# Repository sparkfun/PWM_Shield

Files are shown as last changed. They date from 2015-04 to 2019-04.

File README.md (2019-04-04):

**NOTE:** *This product has been retired from our catalog. If you are looking for more up-to-date info, please check out some of these resources to see how other users are still hacking and improving on this product.*
* *[SparkFun Forum](https://forum.sparkfun.com/)*
* *[Comments Here on GitHub](https://github.com/sparkfun/PWM_Shield/issues)*
* *[IRC Channel](https://www.sparkfun.com/news/263)*

SparkFun PWM Shield
========================================

SparkFun PWM Shield

[*SparkFun PWM Shield (DEV-10615)*](https://www.sparkfun.com/products/10615)

This is the Arduino shield version of our TLC5940 Breakout. 
The SparkFun PWM Shield will allow you to generate up to 16 PWM signals from your Arduino by utilizing the power of the TLC5940 IC. 

Repository Contents
-------------------

* **/Hardware** - Eagle design files (.brd, .sch)
* **/Libraries** - Libraries for use with the TLC5940
* **/Production** - Production panel files (.brd)

Documentation
--------------
* **[Library](https://github.com/sparkfun/SparkFun_TLC5940_Arduino_Library)** - Arduino Library for the TLC5940. 
* **[SparkFun Fritzing repo](https://github.com/sparkfun/Fritzing_Parts)** - Fritzing diagrams for SparkFun products.
* **[SparkFun 3D Model repo](https://github.com/sparkfun/3D_Models)** - 3D models of SparkFun products. 

License Information
-------------------
This product is _**open source**_! 

The **hardware** is released under [Creative Commons ShareAlike 4.0 International](https://creativecommons.org/licenses/by-sa/4.0/).

Please use, reuse, and modify these files as you see fit. Please maintain attribution to SparkFun Electronics and release anything derivative under the same license.

Distributed as-is; no warranty is given.

- Your friends at SparkFun.

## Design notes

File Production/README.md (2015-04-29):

SparkFun Production Files
=========================

These .brd files are the panels we use for producing large numbers of pcbs.

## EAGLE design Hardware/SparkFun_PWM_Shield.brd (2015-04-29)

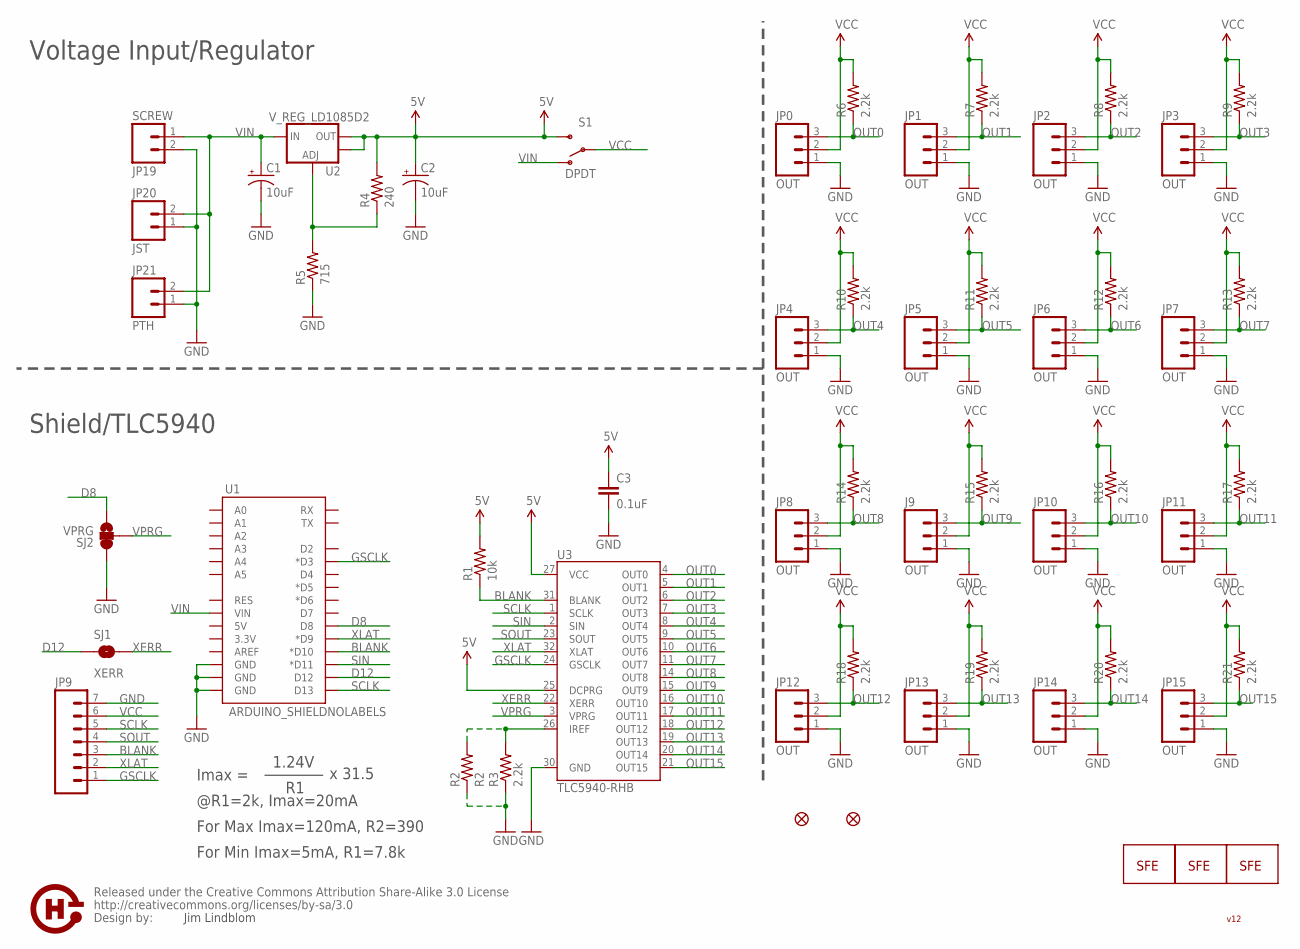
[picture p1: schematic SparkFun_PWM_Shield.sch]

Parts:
C1: 10uF; EIA3528
C2: 10uF; EIA3216
C3: 0.1uF; 0402-CAP
J9: OUT; 1X03
JP0, JP1, JP2, JP3, JP4, JP5, JP6, JP7, JP8, JP10, JP11, JP12, JP13, JP14, JP15: OUT; 1X03
JP9: M07; 1X07
JP16: LOGO-SFENEW; SFE-NEW-WEBLOGO
JP17: LOGO-SFESK; SFE-LOGO-FLAME
JP18: LOGO-SFENW2; SFE-NEW-WEB
JP19: SCREW; SCREWTERMINAL-3.5MM-2-NS
JP20: JST; JST-2-PTH
JP21: PTH; 1X02
JP22, JP23: FIDUCIAL1X2; FIDUCIAL-1X2
R1: 10k; 0402-RES
R2: R2; AXIAL-0.3
R3, R6, R7, R8, R9, R10, R11, R12, R13, R14, R15, R16, R17, R18, R19, R20, R21: 2.2k; 0402-RES
R4: 240; 0402-RES
R5: 715; 0402-RES
S1: DPDT; AYZ0202
SJ1: XERR; SJ_2S-NO
SJ2: VPRG; SJ_3
U1: ARDUINO_SHIELDNOLABELS; DUEMILANOVE_SHIELD_NOLABELS
U2: V_REG_LD1085D2; D2PACK/A
U3: TLC5940-RHB; QFN-32
U$1: OSHW-LOGOORB; OSHW-LOGO-GO
U$2: CREATIVE_COMMONS

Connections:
5V: C2.A (+), C3.1, R1.2, R4.2, S1.3 (S), U2.2 (OUT), U2.TAB (OUT), U3.25 (DCPRG), U3.27 (VCC)
BLANK: JP9.3, R1.1, U1.D10 (*D10), U3.31 (BLANK)
D8: SJ2.3, U1.D8
D12: SJ1.1, U1.D12
GND: C1.C (-), C2.C (-), C3.2, J9.1, JP0.1, JP1.1, JP2.1, JP3.1, JP4.1, JP5.1, JP6.1, JP7.1, JP8.1, JP9.7, JP10.1, JP11.1, JP12.1, JP13.1, JP14.1, JP15.1, JP19.2, JP20.1, JP21.1, R2.P$1 (1), R3.1, R5.1, SJ2.1, U1.GND@0 (GND), U1.GND@1 (GND), U1.GND@2 (GND), U3.30 (GND)
GSCLK: JP9.1, U1.D3 (*D3), U3.24 (GSCLK)
unnamed: R4.1, R5.2, U2.1 (ADJ)
unnamed: R2.P$2 (2), R3.2, U3.26 (IREF)
OUT0: JP0.3, R6.1, U3.4 (OUT0)
OUT1: JP1.3, R7.1, U3.5 (OUT1)
OUT2: JP2.3, R8.1, U3.6 (OUT2)
OUT3: JP3.3, R9.1, U3.7 (OUT3)
OUT4: JP4.3, R10.1, U3.8 (OUT4)
OUT5: JP5.3, R11.1, U3.9 (OUT5)
OUT6: JP6.3, R12.1, U3.10 (OUT6)
OUT7: JP7.3, R13.1, U3.11 (OUT7)
OUT8: JP8.3, R14.1, U3.14 (OUT8)
OUT9: J9.3, R15.1, U3.15 (OUT9)
OUT10: JP10.3, R16.1, U3.16 (OUT10)
OUT11: JP11.3, R17.1, U3.17 (OUT11)
OUT12: JP12.3, R18.1, U3.18 (OUT12)
OUT13: JP13.3, R19.1, U3.19 (OUT13)
OUT14: JP14.3, R20.1, U3.20 (OUT14)
OUT15: JP15.3, R21.1, U3.21 (OUT15)
SCLK: JP9.5, U1.D13, U3.1 (SCLK)
SIN: U1.D11 (*D11), U3.2 (SIN)
SOUT: JP9.4, U3.23 (SOUT)
VCC: J9.2, JP0.2, JP1.2, JP2.2, JP3.2, JP4.2, JP5.2, JP6.2, JP7.2, JP8.2, JP9.6, JP10.2, JP11.2, JP12.2, JP13.2, JP14.2, JP15.2, R6.2, R7.2, R8.2, R9.2, R10.2, R11.2, R12.2, R13.2, R14.2, R15.2, R16.2, R17.2, R18.2, R19.2, R20.2, R21.2, S1.2
VIN: C1.A (+), JP19.1, JP20.2, JP21.2, S1.1 (O), U1.VIN, U2.3 (IN)
VPRG: SJ2.2, U3.3 (VPRG)
XERR: SJ1.2, U3.22 (XERR)
XLAT: JP9.2, U1.D9 (*D9), U3.32 (XLAT)

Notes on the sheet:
Imax =
1.24V
x 31.5
@R1=2k, Imax=20mA
For Max Imax=120mA, R2=390
For Min Imax=5mA, R1=7.8k
Jim Lindblom
Shield/TLC5940
Voltage Input/Regulator
v12

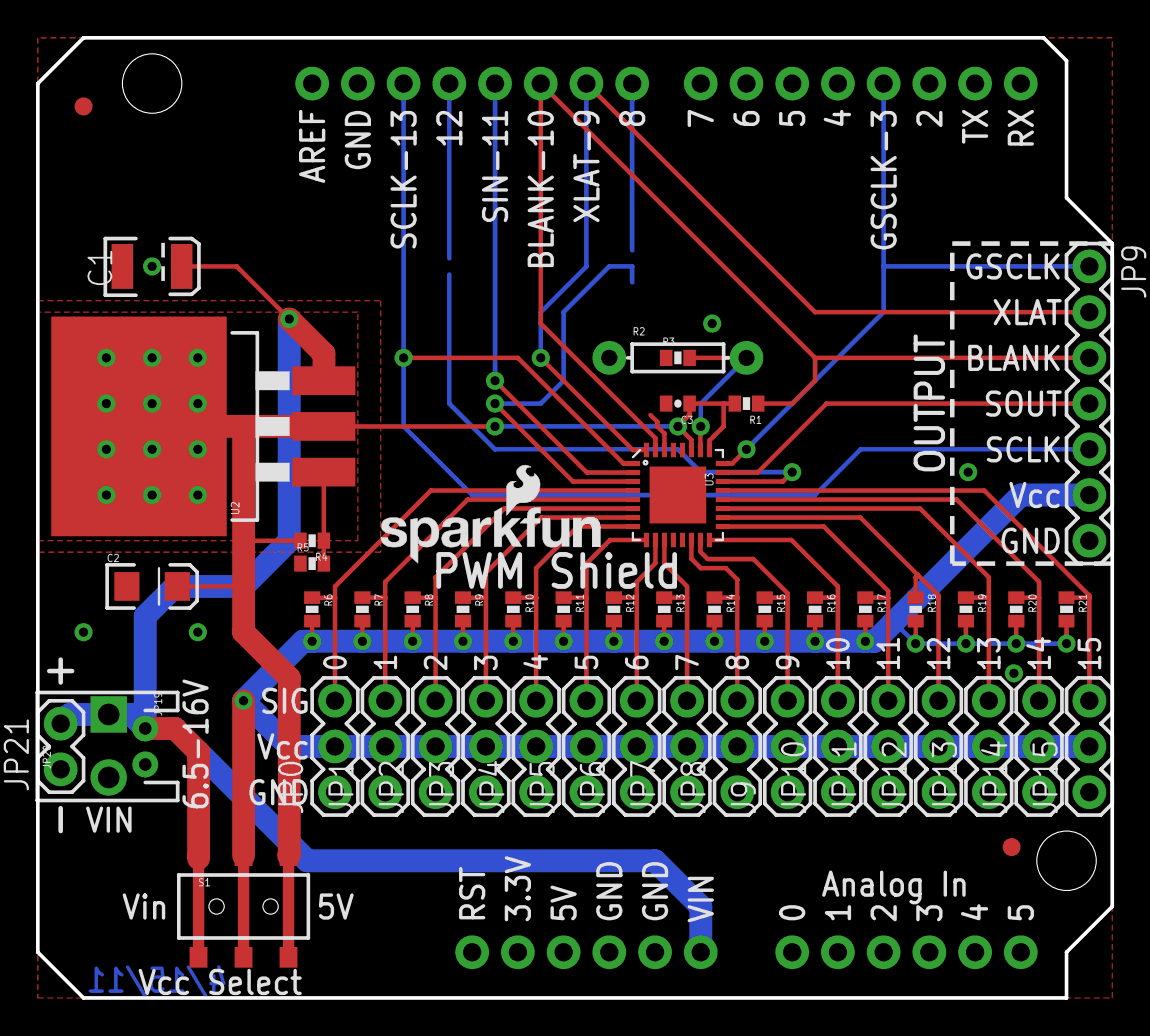
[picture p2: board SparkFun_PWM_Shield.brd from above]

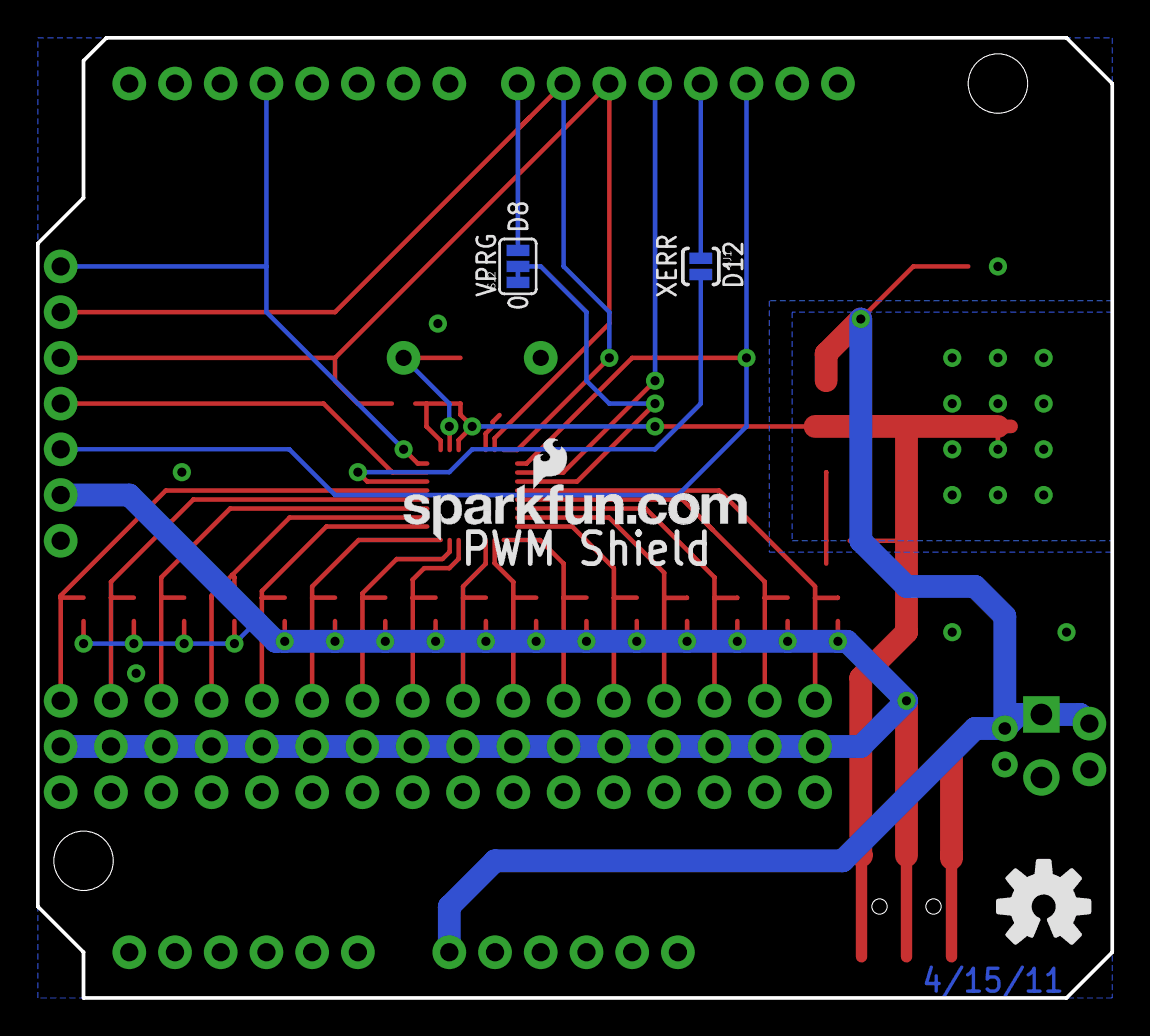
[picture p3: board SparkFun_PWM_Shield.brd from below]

Board: 2 copper layers, 59.7 x 53.3 mm, 57 parts (4 on the bottom side), 32 nets.

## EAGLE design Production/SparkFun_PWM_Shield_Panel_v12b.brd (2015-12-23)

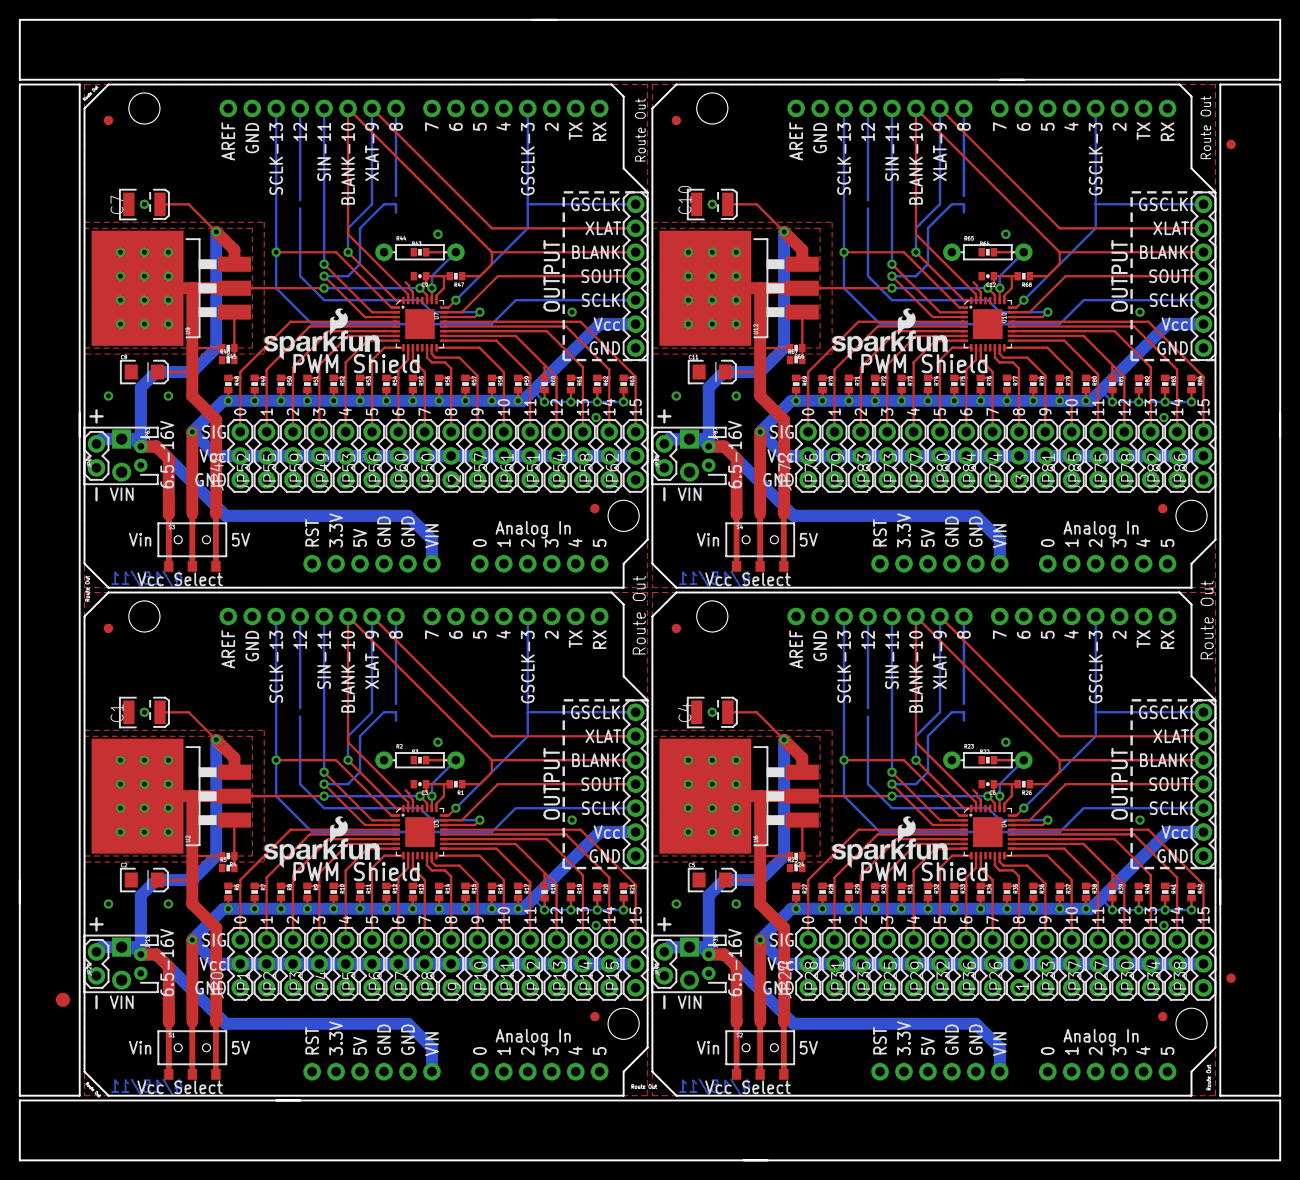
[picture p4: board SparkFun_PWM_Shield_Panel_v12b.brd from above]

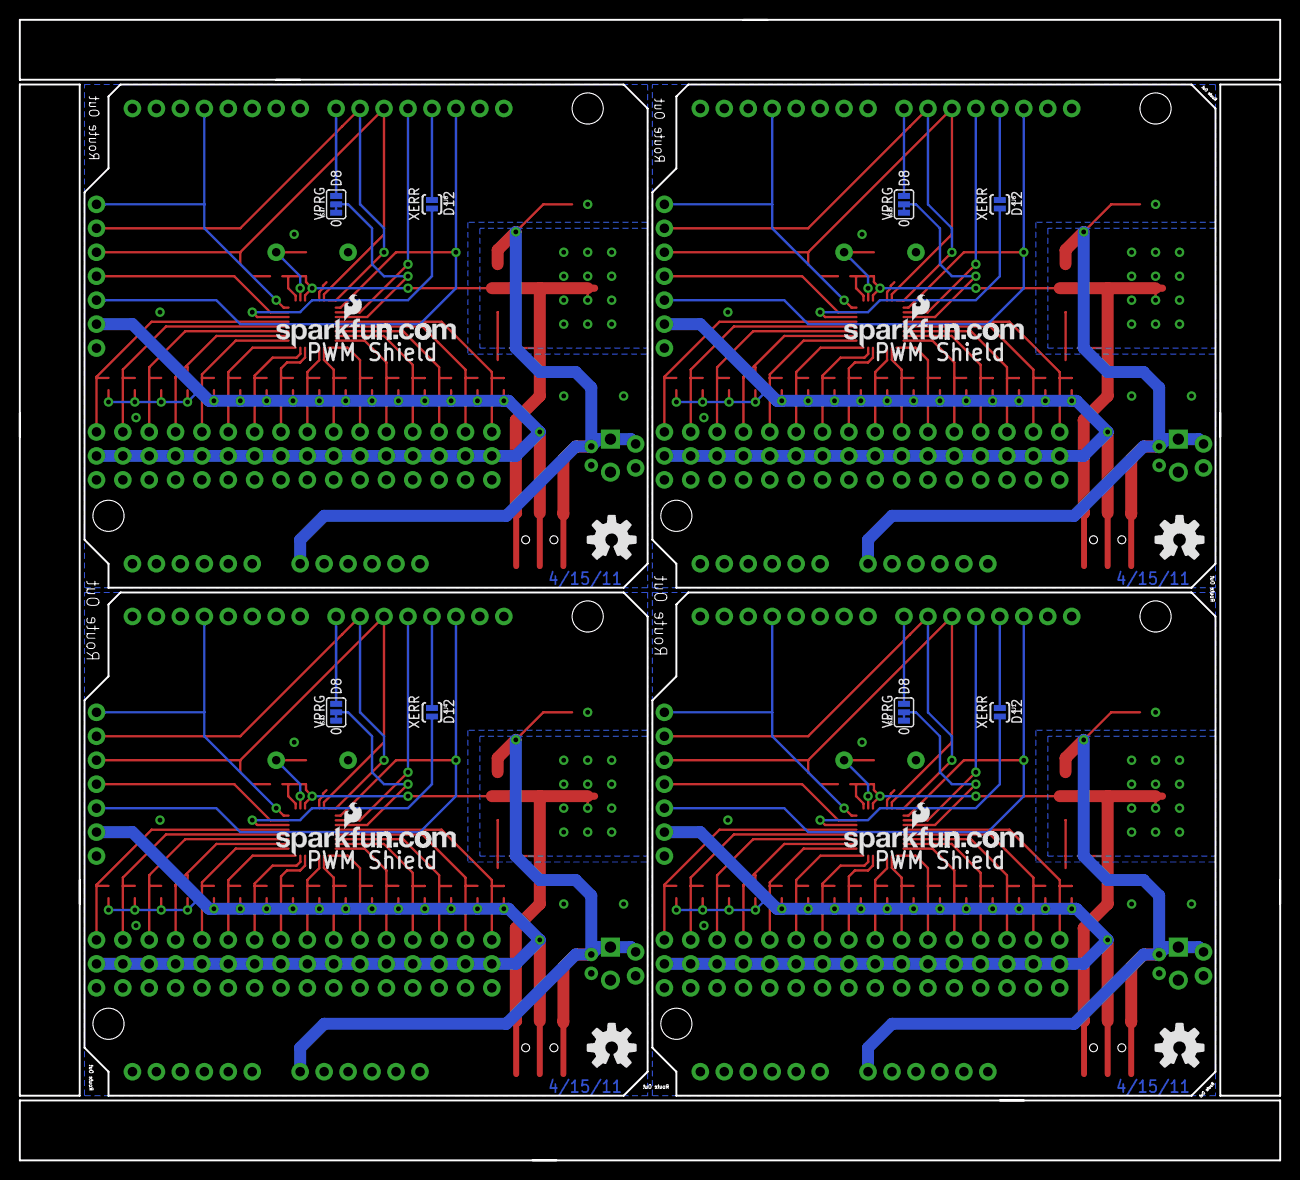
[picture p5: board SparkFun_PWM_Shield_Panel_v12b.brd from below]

Board: 2 copper layers, 133.6 x 120.9 mm, 227 parts (16 on the bottom side), 128 nets.

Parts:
C1, C4, C7, C10: 10uF; EIA3528
C2, C5, C8, C11: 10uF; EIA3216
C3, C6, C9, C12: 0.1uF; 0402-CAP
E$1: FIDUCIAL-1.5X3
E$5, E$6: FIDUCIAL-1X2
J1, J2, J3, J9: OUT; 1X03
JP0, JP1, JP2, JP3, JP4, JP5, JP6, JP7, JP8, JP10, JP11, JP12, JP13, JP14, JP15, JP24, JP25, JP26, JP27, JP28, JP29, JP30, JP31, JP32, JP33, JP34, JP35, JP36, JP37, JP38, JP48, JP49, JP50, JP51, JP52, JP53, JP54, JP55, JP56, JP57, JP58, JP59, JP60, JP61, JP62, JP72, JP73, JP74, JP75, JP76, JP77, JP78, JP79, JP80, JP81, JP82, JP83, JP84, JP85, JP86: OUT; 1X03
JP9, JP43, JP67, JP91: 1X07
JP16, JP44, JP68, JP92: LOGO-SFENEW; SFE-NEW-WEBLOGO
JP17, JP45, JP69, JP93: LOGO-SFESK; SFE-LOGO-FLAME
JP18, JP42, JP66, JP90: LOGO-SFENW2; SFE-NEW-WEB
JP19, JP39, JP63, JP87: SCREW; SCREWTERMINAL-3.5MM-2-NS
JP20, JP40, JP64, JP88: JST; JST-2-PTH
JP21, JP41, JP65, JP89: PTH; 1X02
JP22, JP23, JP46, JP47, JP70, JP71, JP94, JP95: FIDUCIAL1X2; FIDUCIAL-1X2
R1, R26, R47, R68: 10k; 0402-RES
R2, R23, R44, R65: R2; AXIAL-0.3
R3, R6, R7, R8, R9, R10, R11, R12, R13, R14, R15, R16, R17, R18, R19, R20, R21, R22, R27, R28, R29, R30, R31, R32, R33, R34, R35, R36, R37, R38, R39, R40, R41, R42, R43, R48, R49, R50, R51, R52, R53, R54, R55, R56, R57, R58, R59, R60, R61, R62, R63, R64, R69, R70, R71, R72, R73, R74, R75, R76, R77, R78, R79, R80, R81, R82, R83, R84: 2.2k; 0402-RES
R4, R24, R45, R66: 240; 0402-RES
R5, R25, R46, R67: 715; 0402-RES
S1, S2, S3, S4: DPDT; AYZ0202
SJ1, SJ4, SJ6, SJ8: XERR; SJ_2S-NO
SJ2, SJ3, SJ5, SJ7: VPRG; SJ_3
U1, U5, U8, U11: ARDUINO_SHIELDNOLABELS; DUEMILANOVE_SHIELD_NOLABELS
U2, U6, U9, U12: V_REG_LD1085D2; D2PACK/A
U3, U4, U7, U10: TLC5940-RHB; QFN-32
U$1, U$2, U$3, U$4: OSHW-LOGOORB; OSHW-LOGO-GO

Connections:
5V: C2.A, C3.1, R1.2, R4.2, S1.3, U2.2, U2.TAB, U3.25, U3.27
5V1: C5.A, C6.1, R24.2, R26.2, S2.3, U4.25, U4.27, U6.2, U6.TAB
5V2: C8.A, C9.1, R45.2, R47.2, S3.3, U7.25, U7.27, U9.2, U9.TAB
5V3: C11.A, C12.1, R66.2, R68.2, S4.3, U10.25, U10.27, U12.2, U12.TAB
BLANK: JP9.3, R1.1, U1.D10, U3.31
BLANK1: JP43.3, R26.1, U4.31, U5.D10
BLANK2: JP67.3, R47.1, U7.31, U8.D10
BLANK3: JP91.3, R68.1, U10.31, U11.D10
D1: SJ3.3, U5.D8
D2: SJ4.1, U5.D12
D3: SJ5.3, U8.D8
D4: SJ6.1, U8.D12
D5: SJ7.3, U11.D8
D6: SJ8.1, U11.D12
D8: SJ2.3, U1.D8
D12: SJ1.1, U1.D12
GND: C1.C, C2.C, C3.2, J9.1, JP0.1, JP1.1, JP2.1, JP3.1, JP4.1, JP5.1, JP6.1, JP7.1, JP8.1, JP9.7, JP10.1, JP11.1, JP12.1, JP13.1, JP14.1, JP15.1, JP19.2, JP20.1, JP21.1, R2.P$1, R3.1, R5.1, SJ2.1, U1.GND@0, U1.GND@1, U1.GND@2, U3.30
GND1: C4.C, C5.C, C6.2, J1.1, JP24.1, JP25.1, JP26.1, JP27.1, JP28.1, JP29.1, JP30.1, JP31.1, JP32.1, JP33.1, JP34.1, JP35.1, JP36.1, JP37.1, JP38.1, JP39.2, JP40.1, JP41.1, JP43.7, R22.1, R23.P$1, R25.1, SJ3.1, U4.30, U5.GND@0, U5.GND@1, U5.GND@2
GND2: C7.C, C8.C, C9.2, J2.1, JP48.1, JP49.1, JP50.1, JP51.1, JP52.1, JP53.1, JP54.1, JP55.1, JP56.1, JP57.1, JP58.1, JP59.1, JP60.1, JP61.1, JP62.1, JP63.2, JP64.1, JP65.1, JP67.7, R43.1, R44.P$1, R46.1, SJ5.1, U7.30, U8.GND@0, U8.GND@1, U8.GND@2
GND3: C10.C, C11.C, C12.2, J3.1, JP72.1, JP73.1, JP74.1, JP75.1, JP76.1, JP77.1, JP78.1, JP79.1, JP80.1, JP81.1, JP82.1, JP83.1, JP84.1, JP85.1, JP86.1, JP87.2, JP88.1, JP89.1, JP91.7, R64.1, R65.P$1, R67.1, SJ7.1, U10.30, U11.GND@0, U11.GND@1, U11.GND@2
GSCLK: JP9.1, U1.D3, U3.24
GSCLK1: JP43.1, U4.24, U5.D3
GSCLK2: JP67.1, U7.24, U8.D3
GSCLK3: JP91.1, U10.24, U11.D3
unnamed: R22.2, R23.P$2, U4.26
unnamed: R4.1, R5.2, U2.1
unnamed: R24.1, R25.2, U6.1
unnamed: R43.2, R44.P$2, U7.26
unnamed: R45.1, R46.2, U9.1
unnamed: R64.2, R65.P$2, U10.26
unnamed: R66.1, R67.2, U12.1
unnamed: R2.P$2, R3.2, U3.26
OUT0: JP0.3, R6.1, U3.4
OUT1: JP1.3, R7.1, U3.5
OUT2: JP2.3, R8.1, U3.6
OUT3: JP3.3, R9.1, U3.7
OUT4: JP4.3, R10.1, U3.8
OUT5: JP5.3, R11.1, U3.9
OUT6: JP6.3, R12.1, U3.10
OUT7: JP7.3, R13.1, U3.11
OUT8: JP8.3, R14.1, U3.14
OUT9: J9.3, R15.1, U3.15
OUT10: JP10.3, R16.1, U3.16
OUT11: JP11.3, R17.1, U3.17
OUT12: JP12.3, R18.1, U3.18
OUT13: JP13.3, R19.1, U3.19
OUT14: JP14.3, R20.1, U3.20
OUT15: JP15.3, R21.1, U3.21
OUT16: JP24.3, R27.1, U4.4
OUT17: JP31.3, R29.1, U4.6
OUT18: JP28.3, R28.1, U4.5
OUT19: JP35.3, R30.1, U4.7
OUT20: JP25.3, R31.1, U4.8
OUT21: JP29.3, R32.1, U4.9
OUT22: JP32.3, R33.1, U4.10
OUT23: JP36.3, R34.1, U4.11
OUT24: JP26.3, R35.1, U4.14
OUT25: J1.3, R36.1, U4.15
OUT26: JP33.3, R37.1, U4.16
OUT27: JP37.3, R38.1, U4.17
OUT28: JP27.3, R39.1, U4.18
OUT29: JP30.3, R40.1, U4.19
OUT30: JP34.3, R41.1, U4.20
OUT31: JP38.3, R42.1, U4.21
OUT32: JP48.3, R48.1, U7.4
OUT33: JP55.3, R50.1, U7.6
OUT34: JP52.3, R49.1, U7.5
OUT35: JP59.3, R51.1, U7.7
OUT36: JP49.3, R52.1, U7.8
OUT37: JP53.3, R53.1, U7.9
OUT38: JP56.3, R54.1, U7.10
OUT39: JP60.3, R55.1, U7.11
OUT40: JP50.3, R56.1, U7.14
OUT41: J2.3, R57.1, U7.15
OUT42: JP57.3, R58.1, U7.16
OUT43: JP61.3, R59.1, U7.17
OUT44: JP51.3, R60.1, U7.18
OUT45: JP54.3, R61.1, U7.19
OUT46: JP58.3, R62.1, U7.20
OUT47: JP62.3, R63.1, U7.21
OUT48: JP72.3, R69.1, U10.4
OUT49: JP79.3, R71.1, U10.6
OUT50: JP76.3, R70.1, U10.5
OUT51: JP83.3, R72.1, U10.7
OUT52: JP73.3, R73.1, U10.8
OUT53: JP77.3, R74.1, U10.9
OUT54: JP80.3, R75.1, U10.10
OUT55: JP84.3, R76.1, U10.11
OUT56: JP74.3, R77.1, U10.14
OUT57: J3.3, R78.1, U10.15
OUT58: JP81.3, R79.1, U10.16
OUT59: JP85.3, R80.1, U10.17
OUT60: JP75.3, R81.1, U10.18
OUT61: JP78.3, R82.1, U10.19
OUT62: JP82.3, R83.1, U10.20
OUT63: JP86.3, R84.1, U10.21
SCLK: JP9.5, U1.D13, U3.1
SCLK1: JP43.5, U4.1, U5.D13
SCLK2: JP67.5, U7.1, U8.D13
SCLK3: JP91.5, U10.1, U11.D13
SIN: U1.D11, U3.2
SIN1: U4.2, U5.D11
SIN2: U7.2, U8.D11
SIN3: U10.2, U11.D11
SOUT: JP9.4, U3.23
SOUT1: JP43.4, U4.23
SOUT2: JP67.4, U7.23
SOUT3: JP91.4, U10.23
VCC: J9.2, JP0.2, JP1.2, JP2.2, JP3.2, JP4.2, JP5.2, JP6.2, JP7.2, JP8.2, JP9.6, JP10.2, JP11.2, JP12.2, JP13.2, JP14.2, JP15.2, R6.2, R7.2, R8.2, R9.2, R10.2, R11.2, R12.2, R13.2, R14.2, R15.2, R16.2, R17.2, R18.2, R19.2, R20.2, R21.2, S1.2
VCC1: J1.2, JP24.2, JP25.2, JP26.2, JP27.2, JP28.2, JP29.2, JP30.2, JP31.2, JP32.2, JP33.2, JP34.2, JP35.2, JP36.2, JP37.2, JP38.2, JP43.6, R27.2, R28.2, R29.2, R30.2, R31.2, R32.2, R33.2, R34.2, R35.2, R36.2, R37.2, R38.2, R39.2, R40.2, R41.2, R42.2, S2.2
VCC2: J2.2, JP48.2, JP49.2, JP50.2, JP51.2, JP52.2, JP53.2, JP54.2, JP55.2, JP56.2, JP57.2, JP58.2, JP59.2, JP60.2, JP61.2, JP62.2, JP67.6, R48.2, R49.2, R50.2, R51.2, R52.2, R53.2, R54.2, R55.2, R56.2, R57.2, R58.2, R59.2, R60.2, R61.2, R62.2, R63.2, S3.2
VCC3: J3.2, JP72.2, JP73.2, JP74.2, JP75.2, JP76.2, JP77.2, JP78.2, JP79.2, JP80.2, JP81.2, JP82.2, JP83.2, JP84.2, JP85.2, JP86.2, JP91.6, R69.2, R70.2, R71.2, R72.2, R73.2, R74.2, R75.2, R76.2, R77.2, R78.2, R79.2, R80.2, R81.2, R82.2, R83.2, R84.2, S4.2
VIN: C1.A, JP19.1, JP20.2, JP21.2, S1.1, U1.VIN, U2.3
VIN1: C4.A, JP39.1, JP40.2, JP41.2, S2.1, U5.VIN, U6.3
VIN2: C7.A, JP63.1, JP64.2, JP65.2, S3.1, U8.VIN, U9.3
VIN3: C10.A, JP87.1, JP88.2, JP89.2, S4.1, U11.VIN, U12.3
VPRG: SJ2.2, U3.3
VPRG1: SJ3.2, U4.3
VPRG2: SJ5.2, U7.3
VPRG3: SJ7.2, U10.3
XERR: SJ1.2, U3.22
XERR1: SJ4.2, U4.22
XERR2: SJ6.2, U7.22
XERR3: SJ8.2, U10.22
XLAT: JP9.2, U1.D9, U3.32
XLAT1: JP43.2, U4.32, U5.D9
XLAT2: JP67.2, U7.32, U8.D9
XLAT3: JP91.2, U10.32, U11.D9

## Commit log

2015-04-29 Initial board file commit
    [SparkFun_PWM_Shield.brd, SparkFun_PWM_Shield.sch]
2015-04-29 Squashed 'Libraries/Arduino/' content from commit 09ea0f2
    git-subtree-dir: Libraries/Arduino
    git-subtree-split: 09ea0f29b5f23ba79426c3c33b837437829adf9c
2015-06-08 Squashed 'Libraries/Arduino/' changes from 09ea0f2..7814504
    7814504 Fixing library.properties file
    git-subtree-split: 78145041dbf402e7b9f9ce5dbe52a36ebba0e697
    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
2015-10-05 Squashed 'Libraries/Arduino/' changes from 7814504..7c3d8c7
    7c3d8c7 Fixing compilation error
    84f472c Fixing library.properties to enable loading in Arduino IDE
    git-subtree-split: 7c3d8c7861b762511ad4b3e899ffde8689cd396d
    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
2015-12-23 created panel v12b
    [SparkFun_PWM_Shield_Panel_v12b.brd]
2016-01-11 Squashed 'Libraries/Arduino/' changes from 7c3d8c7..18a0c0f
    18a0c0f Updating file names for codebender fix
    git-subtree-split: 18a0c0fa8911f19f615ccea7981273a6ffd0adf4
    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

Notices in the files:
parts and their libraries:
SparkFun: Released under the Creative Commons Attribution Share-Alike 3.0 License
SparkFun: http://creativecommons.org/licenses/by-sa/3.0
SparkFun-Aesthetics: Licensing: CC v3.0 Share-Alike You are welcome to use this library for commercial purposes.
